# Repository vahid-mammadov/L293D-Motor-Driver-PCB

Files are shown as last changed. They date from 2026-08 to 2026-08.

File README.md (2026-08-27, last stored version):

# L293D Motor Driver PCB

## Overview
A custom motor driver PCB designed for controlling DC motors using the **L293D H-Bridge motor driver**. 
The board was designed as part of an embedded systems and electronics development project.

## Features
Dual DC motor control using L293D
H-Bridge motor driver configuration
74HC595 shift register for digital output expansion
External power and motor connection interfaces
Custom schematic and PCB layout

## Tools & Technologies
**KiCad**
PCB Design
Electronic Circuit Design
L293D H-Bridge Motor Driver
74HC595 Shift Register

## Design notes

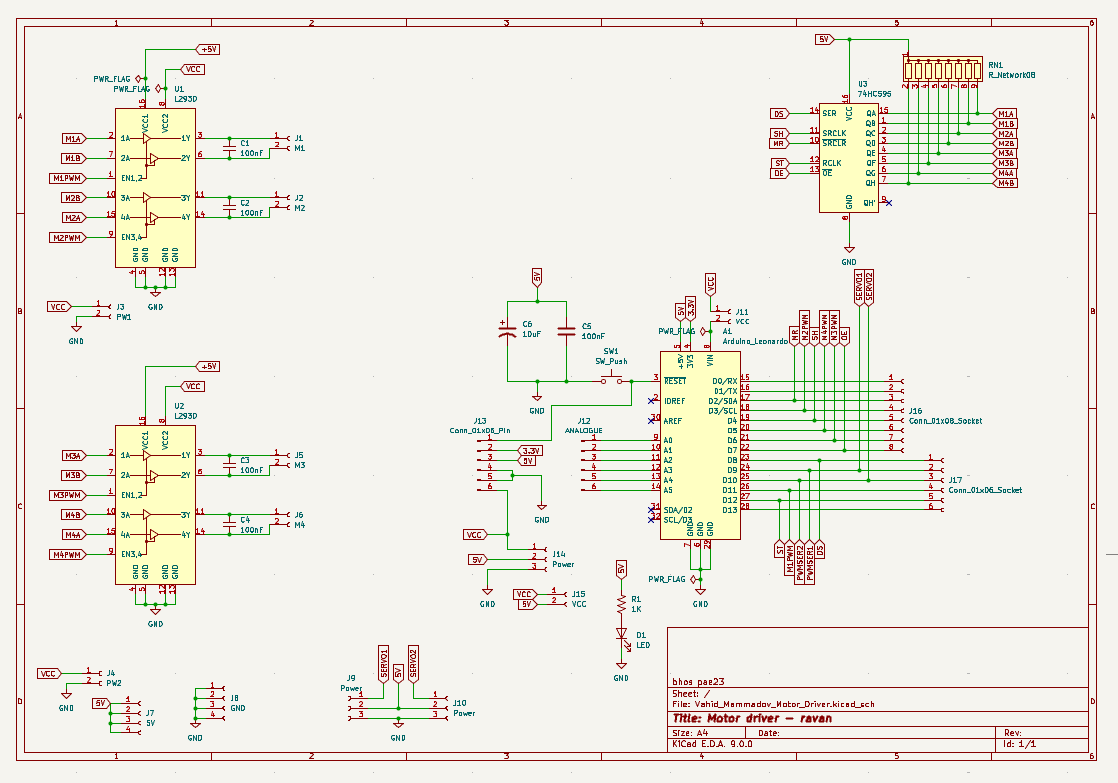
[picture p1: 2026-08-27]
Images/Schematic_View.png

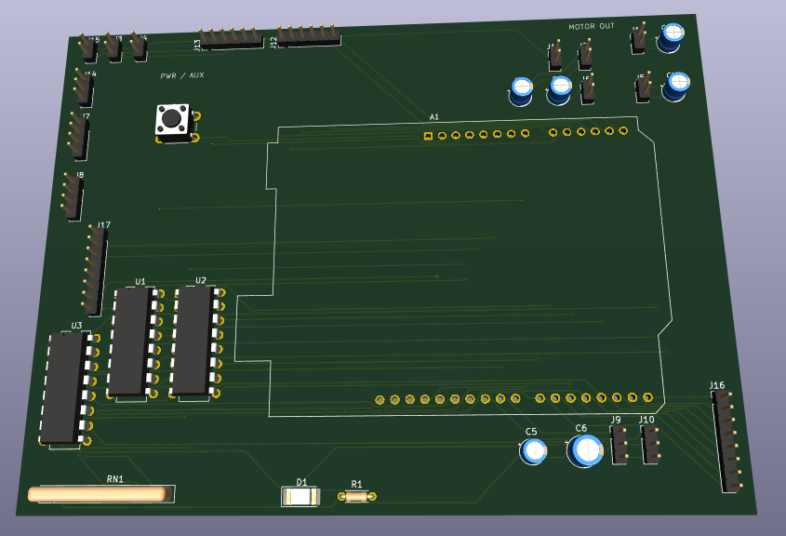
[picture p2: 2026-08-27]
Images/3D_View.png

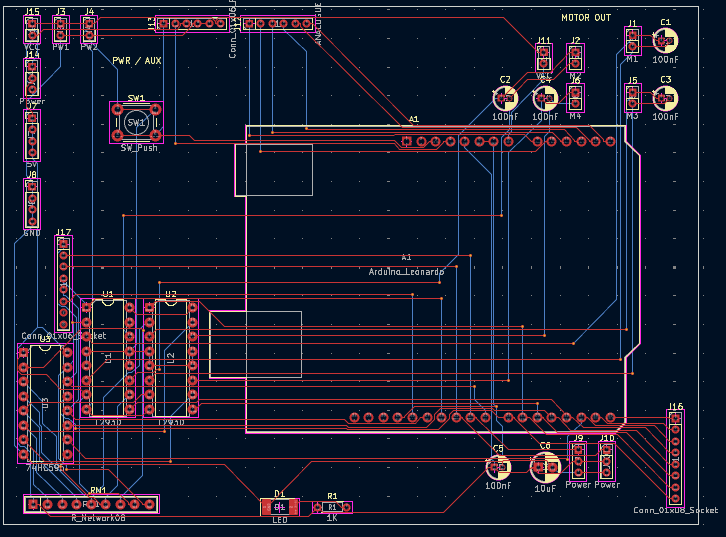
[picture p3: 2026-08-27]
Images/PCB_View.png

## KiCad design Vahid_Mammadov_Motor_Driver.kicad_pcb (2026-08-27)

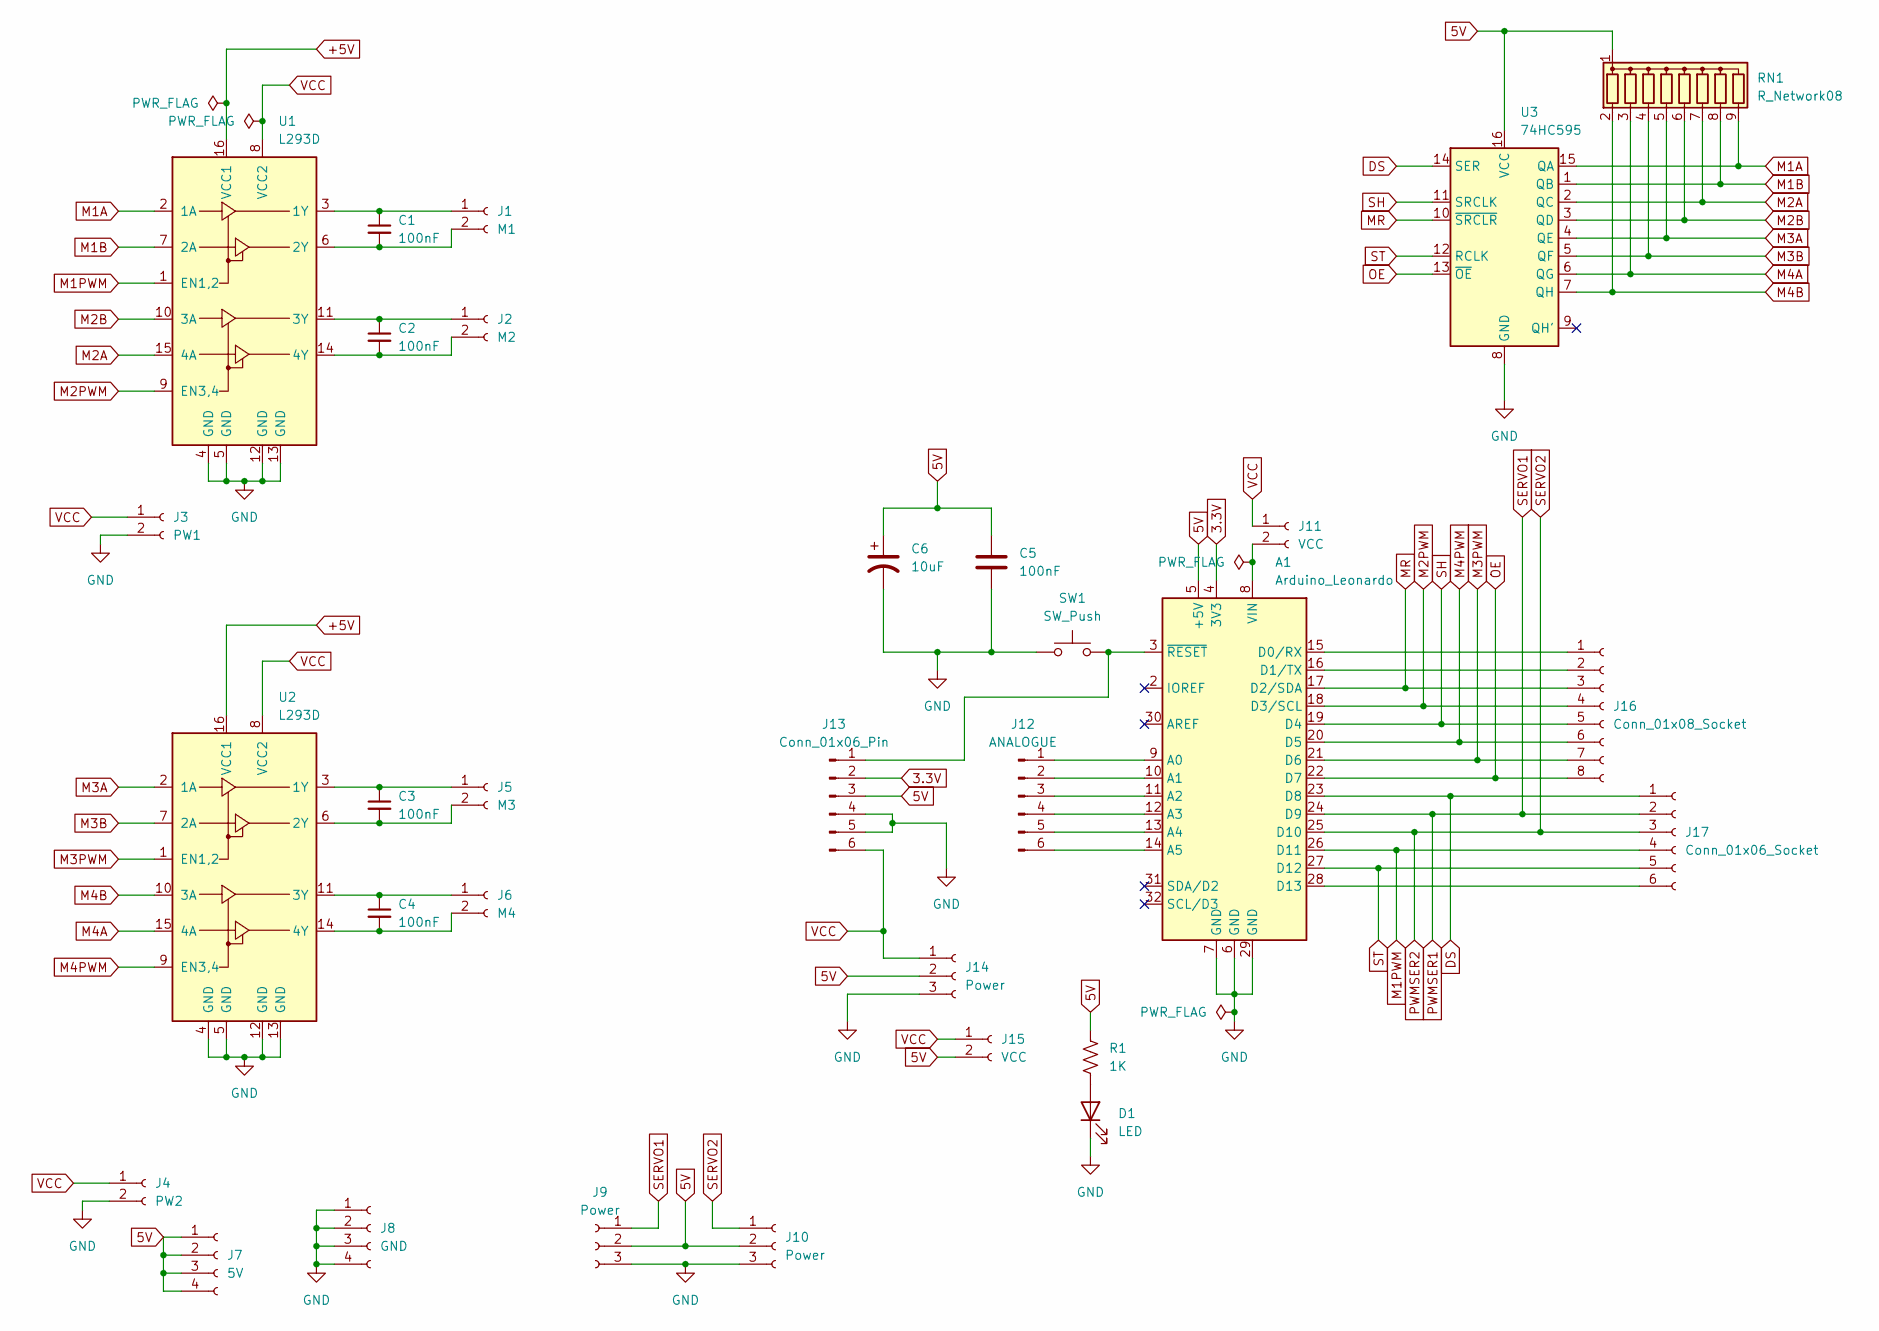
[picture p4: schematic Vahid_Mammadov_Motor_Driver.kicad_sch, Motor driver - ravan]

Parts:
A1: Arduino_Leonardo; Arduino_UNO_R3
C1, C2, C3, C4, C5: 100nF; CP_Radial_D4.0mm_P1.50mm
C6: 10uF; CP_Radial_D5.0mm_P2.50mm
D1: LED; LED_2010_5025Metric_Pad1.52x2.65mm_HandSolder
J1: M1; PinHeader_1x02_P2.00mm_Vertical
J2: M2; PinHeader_1x02_P2.00mm_Vertical
J3: PW1; PinHeader_1x02_P2.00mm_Vertical
J4: PW2; PinHeader_1x02_P2.00mm_Vertical
J5: M3; PinHeader_1x02_P2.00mm_Vertical
J6: M4; PinHeader_1x02_P2.00mm_Vertical
J7: 5V; PinHeader_1x04_P2.00mm_Vertical
J8: GND; PinHeader_1x04_P2.00mm_Vertical
J9, J10, J14: Power; PinHeader_1x03_P2.00mm_Vertical
J11, J15: VCC; PinHeader_1x02_P2.00mm_Vertical
J12: ANALOGUE; PinHeader_1x06_P2.00mm_Vertical
J13: Conn_01x06_Pin; PinHeader_1x06_P2.00mm_Vertical
J16: Conn_01x08_Socket; PinHeader_1x08_P2.00mm_Vertical
J17: Conn_01x06_Socket; PinHeader_1x08_P2.00mm_Vertical
R1: 1K; R_Axial_DIN0204_L3.6mm_D1.6mm_P5.08mm_Horizontal
RN1: R_Network08; R_Array_SIP9
SW1: SW_Push; SW_PUSH_6mm
U1, U2: L293D; DIP-16_W7.62mm
U3: 74HC595; DIP-16_W7.62mm

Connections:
3.3V: A1.4 (3V3), J13.2
5V: A1.5 (+5V), C5.1, C6.1, J7.1, J7.2, J7.3, J7.4, J9.2, J10.2, J13.3, J14.2, J15.2, R1.1, RN1.1 (common), U3.16 (VCC)
+5V: U1.16 (VCC1), U2.16 (VCC1)
DS: A1.23 (D8), J17.1, U3.14 (SER)
GND: A1.6 (GND), A1.7 (GND), A1.29 (GND), C5.2, C6.2, D1.1 (K), J3.2, J4.2, J8.1, J8.2, J8.3, J8.4, J9.3, J10.3, J13.4, J13.5, J14.3, SW1.1, U1.4 (GND), U1.5 (GND), U1.12 (GND), U1.13 (GND), U2.4 (GND), U2.5 (GND), U2.12 (GND), U2.13 (GND), U3.8 (GND)
M1A: RN1.9 (R8), U1.2 (1A), U3.15 (QA)
M1B: RN1.8 (R7), U1.7 (2A), U3.1 (QB)
M1PWM: A1.26 (D11), J17.4, U1.1 (EN1,2)
M2A: RN1.7 (R6), U1.15 (4A), U3.2 (QC)
M2B: RN1.6 (R5), U1.10 (3A), U3.3 (QD)
M2PWM: A1.18 (D3/SCL), J16.4, U1.9 (EN3,4)
M3A: RN1.5 (R4), U2.2 (1A), U3.4 (QE)
M3B: RN1.4 (R3), U2.7 (2A), U3.5 (QF)
M3PWM: A1.21 (D6), J16.7, U2.1 (EN1,2)
M4A: RN1.3 (R2), U2.15 (4A), U3.6 (QG)
M4B: RN1.2 (R1), U2.10 (3A), U3.7 (QH)
M4PWM: A1.20 (D5), J16.6, U2.9 (EN3,4)
MR: A1.17 (D2/SDA), J16.3, U3.10 (~SRCLR)
unnamed: A1.9 (A0), J12.1
unnamed: A1.10 (A1), J12.2
unnamed: A1.11 (A2), J12.3
unnamed: A1.12 (A3), J12.4
unnamed: A1.13 (A4), J12.5
unnamed: A1.14 (A5), J12.6
unnamed: A1.15 (D0/RX), J16.1
unnamed: A1.16 (D1/TX), J16.2
unnamed: A1.28 (D13), J17.6
unnamed: A1.8 (VIN), J11.2
unnamed: A1.3 (~RESET), J13.1, SW1.2
unnamed: D1.2 (A), R1.2
unnamed: C1.1, J1.1, U1.3 (1Y)
unnamed: C1.2, J1.2, U1.6 (2Y)
unnamed: C2.1, J2.1, U1.11 (3Y)
unnamed: C2.2, J2.2, U1.14 (4Y)
unnamed: C3.1, J5.1, U2.3 (1Y)
unnamed: C3.2, J5.2, U2.6 (2Y)
unnamed: C4.1, J6.1, U2.11 (3Y)
unnamed: C4.2, J6.2, U2.14 (4Y)
OE: A1.22 (D7), J16.8, U3.13 (~OE)
PWMSER1: A1.24 (D9), J9.1, J17.2
PWMSER2: A1.25 (D10), J10.1, J17.3
SH: A1.19 (D4), J16.5, U3.11 (SRCLK)
ST: A1.27 (D12), J17.5, U3.12 (RCLK)
VCC: J3.1, J4.1, J11.1, J13.6, J14.1, J15.1, U1.8 (VCC2), U2.8 (VCC2)

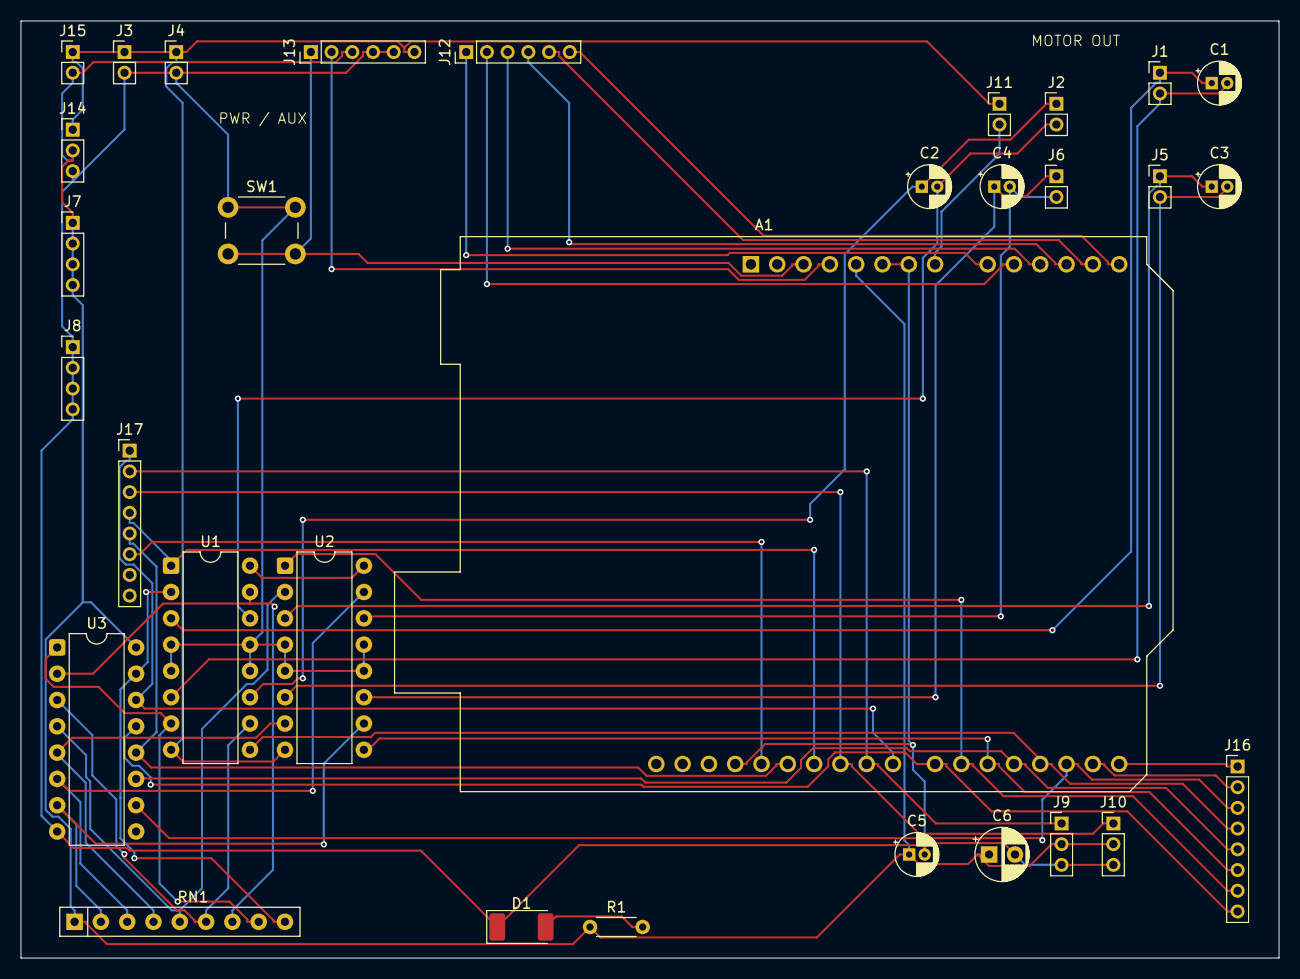
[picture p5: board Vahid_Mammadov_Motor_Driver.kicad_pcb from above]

Board: 2 copper layers, 121.5 x 90.5 mm, 31 parts (0 on the bottom side), 44 nets.
